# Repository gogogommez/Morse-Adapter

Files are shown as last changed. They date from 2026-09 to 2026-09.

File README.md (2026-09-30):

# Morse-Adapter

USB-HID adapter for connecting an iambic Morse paddle to a computer or mobile device using a **Raspberry Pi Pico / RP2040**.

Developed by **Roland Schaal**.

## Features

- **Morse Mania:** left paddle = `a`, right paddle = `s`
- **VBand / Morse Invaders:** left paddle = `[`, right paddle = `]`
- Simultaneous paddle input (squeezing) is supported
- Hold both paddles for **15 seconds** to switch mode
- The selected mode is stored in EEPROM
- LED indication: 1 blink = Morse Mania, 2 blinks = VBand / Morse Invaders

## Wiring

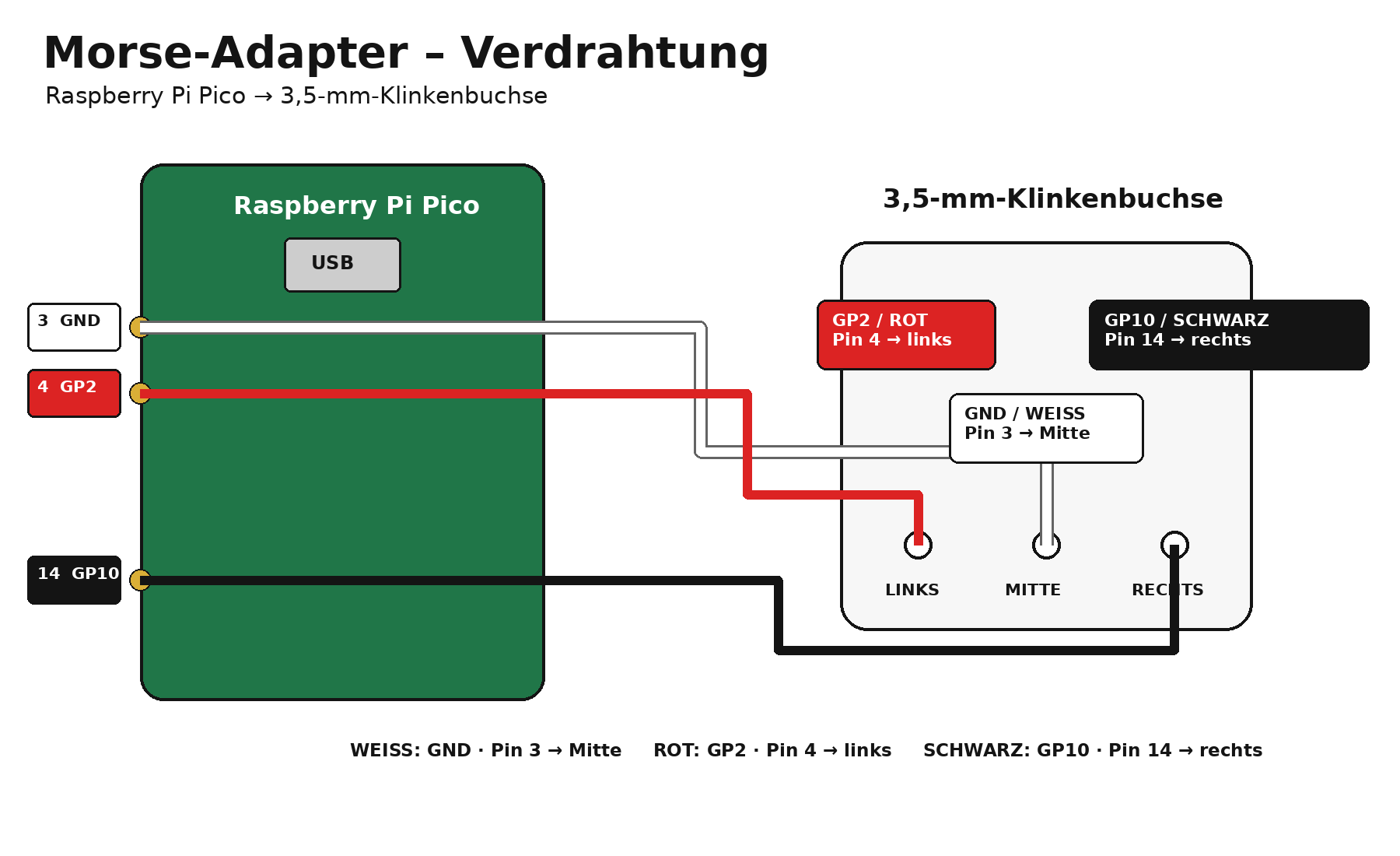
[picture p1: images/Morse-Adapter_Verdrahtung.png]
Morse-Adapter wiring diagram


| Raspberry Pi Pico | Cable color | 3.5 mm TRS connection |
| --- | --- | --- |
| **GP2 – physical Pin 4** | 🔴 Red | **Tip** |
| **GND – physical Pin 3** | ⚪ White | **Sleeve** |
| **GP10 – physical Pin 14** | ⚫ Black | **Ring** |

```text
Raspberry Pi Pico                 3.5 mm TRS jack

GP2  – Pin 4  ───── RED ───────► TIP
GND  – Pin 3  ───── WHITE ─────► SLEEVE
GP10 – Pin 14 ───── BLACK ─────► RING
```

There are exactly three connections. The inputs use the Pico's internal pull-up resistors; the paddle contacts switch the corresponding GPIO to GND.

## Parts list

- 1× Raspberry Pi Pico / RP2040
- 1× 3.5 mm stereo jack socket for the Morse paddle
- 1× USB cable suitable for the Raspberry Pi Pico
- Hook-up wire
- Solder
- 1× 3D-printed enclosure (base and cover)

## Arduino IDE setup

Use the **Raspberry Pi Pico/RP2040 Arduino Core by Earle F. Philhower**.

Select: `Tools -> USB Stack -> Adafruit TinyUSB`

The sketch uses `Keyboard.h` and `EEPROM.h`.

## Firmware

The firmware is in [Morse-Adapter.ino](Morse-Adapter.ino).

### Mode switching

Both paddles remain fully usable for normal iambic squeezing. If both paddles are held continuously for **15 seconds**, the adapter releases the current HID keys, changes mode, stores the new mode in EEPROM and indicates it with the onboard LED. Both paddles must then be released before normal input resumes.

## 3D printed enclosure

The enclosure was designed for this adapter. Source/print files:

- `Gehaeuse_Morse_Adapter_2_v16_001.3mf`
- `Gehaeuse_Morse_Adapter_2_v16_001.step`
- `Gehaeuse_Morse_Adapter_2_v16_002.step`

## Photos

Project photos show the finished adapter, the Raspberry Pi Pico inside the enclosure, and the wiring between the Pico and the 3.5 mm paddle jack.

## Author

**Roland Schaal**

The **Morse-Adapter firmware and project** are developed by Roland Schaal.

The Raspberry Pi Pico/RP2040 Arduino Core used to compile the firmware is developed by **Earle F. Philhower**.

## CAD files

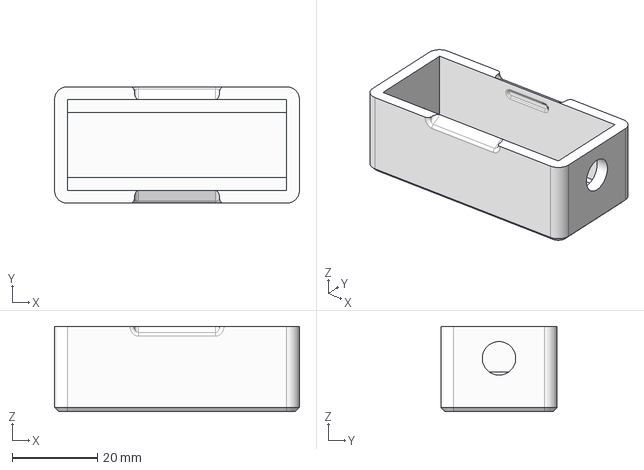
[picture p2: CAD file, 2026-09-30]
3d/Gehäuse_Morse_Adapter_2_v16_002.step
57.4 x 27.2 x 20.0 mm

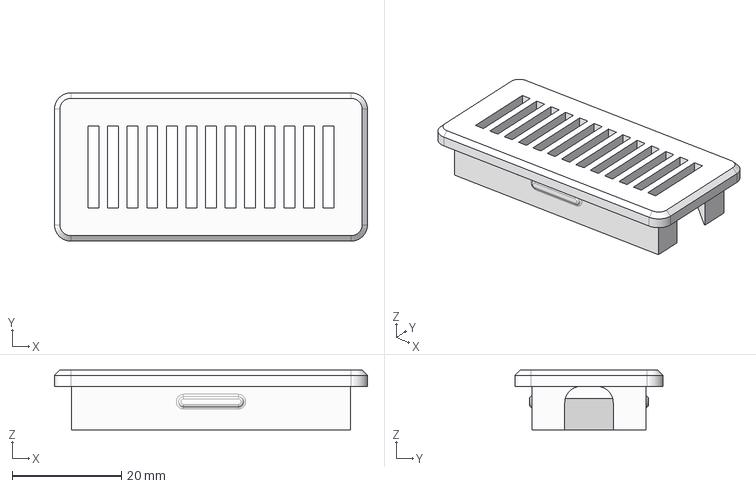
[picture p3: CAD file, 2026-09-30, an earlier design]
3d/Gehäuse_Morse_Adapter_2_v16_001.step
57.4 x 27.2 x 11.0 mm

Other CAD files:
3d/Gehäuse_Morse_Adapter_2_v16_001.3mf

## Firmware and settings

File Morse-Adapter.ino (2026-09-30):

// Morse Adapter
// Raspberry Pi Pico / RP2040
//
// Developed by Roland Schaal
//
// Arduino Core:
// "Raspberry Pi Pico/RP2040" by Earle F. Philhower
//
// Important:
// Tools -> USB Stack -> Adafruit TinyUSB
//
// Wiring:
// Left paddle  -> GP10 -> GND
// Right paddle -> GP2  -> GND
//
// Modes:
// 1 = Morse Mania
//     Left  -> a
//     Right -> s
//
// 2 = VBand / Morse Invaders
//     Left  -> [
//     Right -> ]
//
// Squeezing:
// Both paddles can be pressed simultaneously.
//
// Mode switch:
// Hold both paddles simultaneously for 15 seconds.
//
// The selected mode is stored in EEPROM.

#include <Keyboard.h>
#include <EEPROM.h>

constexpr uint8_t LEFT_PIN  = 10;
constexpr uint8_t RIGHT_PIN = 2;

constexpr uint32_t DEBOUNCE_MS = 8;
constexpr uint32_t MODE_SWITCH_MS = 15000;

constexpr uint8_t EEPROM_SIZE = 16;
constexpr uint8_t EEPROM_ADDR = 0;

enum PaddleMode {
  MORSE_MANIA = 0,
  VBAND = 1
};

PaddleMode currentMode = MORSE_MANIA;

struct PaddleInput {
  uint8_t pin;
  bool rawState;
  bool stableState;
  uint32_t lastChange;
};

PaddleInput leftPaddle;
PaddleInput rightPaddle;

bool bothPressedActive = false;
bool modeAlreadySwitched = false;
uint32_t bothPressedSince = 0;

#ifndef LED_BUILTIN
#define LED_BUILTIN 25
#endif

char getLeftKey() {
  if (currentMode == MORSE_MANIA) return 'a';
  return '[';
}

char getRightKey() {
  if (currentMode == MORSE_MANIA) return 's';
  return ']';
}

void blinkLED(uint8_t count) {
  for (uint8_t i = 0; i < count; i++) {
    digitalWrite(LED_BUILTIN, HIGH);
    delay(150);
    digitalWrite(LED_BUILTIN, LOW);
    delay(200);
  }
}

void showCurrentMode() {
  if (currentMode == MORSE_MANIA) blinkLED(1);
  else blinkLED(2);
}

void saveMode() {
  EEPROM.write(EEPROM_ADDR, static_cast<uint8_t>(currentMode));
  EEPROM.commit();
}

void loadMode() {
  uint8_t saved = EEPROM.read(EEPROM_ADDR);
  if (saved == MORSE_MANIA || saved == VBAND) {
    currentMode = static_cast<PaddleMode>(saved);
  } else {
    currentMode = MORSE_MANIA;
    saveMode();
  }
}

void initPaddle(PaddleInput &paddle, uint8_t pin) {
  paddle.pin = pin;
  pinMode(pin, INPUT_PULLUP);
  paddle.rawState = digitalRead(pin);
  paddle.stableState = paddle.rawState;
  paddle.lastChange = millis();
}

bool updatePaddle(PaddleInput &paddle) {
  bool raw = digitalRead(paddle.pin);

  if (raw != paddle.rawState) {
    paddle.rawState = raw;
    paddle.lastChange = millis();
  }

  if (millis() - paddle.lastChange >= DEBOUNCE_MS) {
    if (paddle.stableState != paddle.rawState) {
      paddle.stableState = paddle.rawState;
      return true;
    }
  }
  return false;
}

void releaseAllPaddleKeys() {
  Keyboard.release('a');
  Keyboard.release('s');
  Keyboard.release('[');
  Keyboard.release(']');
}

void setup() {
  pinMode(LED_BUILTIN, OUTPUT);
  digitalWrite(LED_BUILTIN, LOW);

  EEPROM.begin(EEPROM_SIZE);
  loadMode();

  initPaddle(leftPaddle, LEFT_PIN);
  initPaddle(rightPaddle, RIGHT_PIN);

  delay(700);
  Keyboard.begin();
  delay(300);
  Keyboard.releaseAll();

  showCurrentMode();
}

void loop() {
  bool leftChanged = updatePaddle(leftPaddle);
  bool rightChanged = updatePaddle(rightPaddle);

  bool leftPressed = leftPaddle.stableState == LOW;
  bool rightPressed = rightPaddle.stableState == LOW;

  if (modeAlreadySwitched) {
    releaseAllPaddleKeys();

    if (!leftPressed && !rightPressed) {
      modeAlreadySwitched = false;
      bothPressedActive = false;
    }
    return;
  }

  // Normal paddle output. Both keys may be held simultaneously for squeezing.
  if (leftChanged) {
    if (leftPressed) Keyboard.press(getLeftKey());
    else Keyboard.release(getLeftKey());
  }

  if (rightChanged) {
    if (rightPressed) Keyboard.press(getRightKey());
    else Keyboard.release(getRightKey());
  }

  if (leftPressed && rightPressed) {
    if (!bothPressedActive) {
      bothPressedActive = true;
      bothPressedSince = millis();
    }

    if (millis() - bothPressedSince >= MODE_SWITCH_MS) {
      releaseAllPaddleKeys();

      if (currentMode == MORSE_MANIA) currentMode = VBAND;
      else currentMode = MORSE_MANIA;

      saveMode();
      showCurrentMode();

      modeAlreadySwitched = true;
      return;
    }
  } else {
    bothPressedActive = false;
  }
}

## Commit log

2026-09-30 Expand documentation with wiring, parts and enclosure files
2026-09-30 Add wiring diagram and TRS wiring table
2026-10-14 Use new wiring schematic in README
    Claude-Session: https://claude.ai/code/session_01Xn3vrdLacq8qjgtFzyZcPQ
2026-10-14 Point README to updated schematic image
    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
